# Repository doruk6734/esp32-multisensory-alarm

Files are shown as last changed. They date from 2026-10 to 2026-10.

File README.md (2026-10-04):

# ESP32 Multisensory Alarm

An ESP32-S3 based alarm system that combines **high-power light, airflow, and an optional active buzzer** to create a configurable wake-up sequence.

The system includes Blynk remote control, an I2C LCD, physical buttons, status LEDs, custom CAD, and an electrical schematic.

<p align="center">
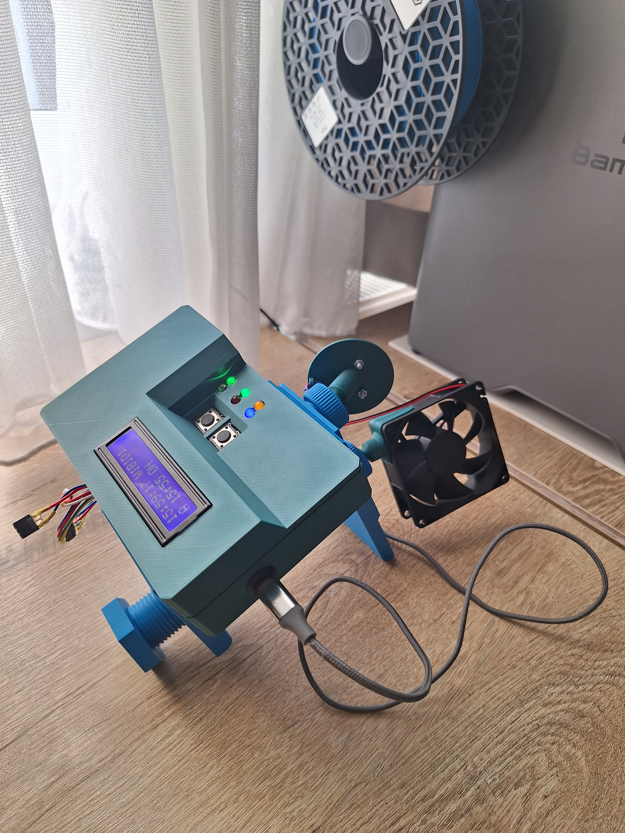
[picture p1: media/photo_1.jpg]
  
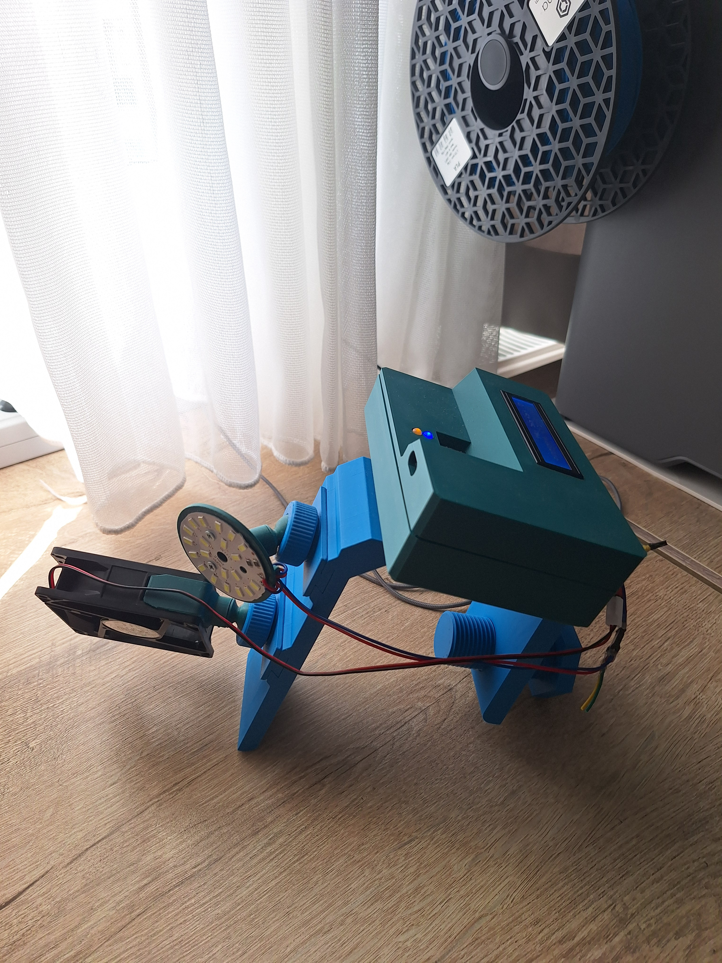
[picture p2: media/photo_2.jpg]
  
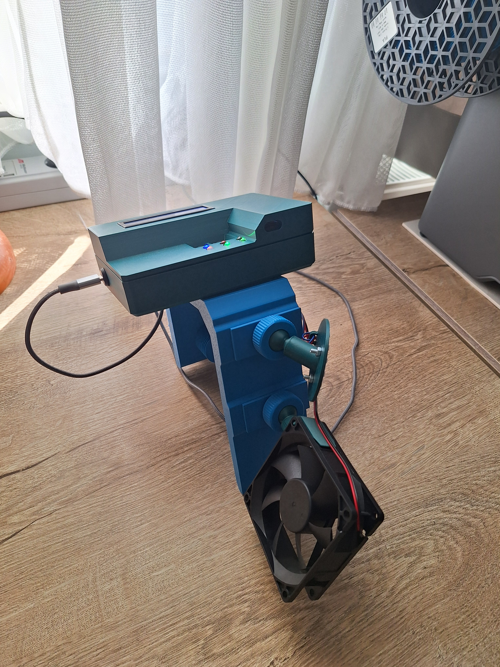
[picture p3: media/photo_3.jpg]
  
</p>

## Features

- ESP32-S3 controller
- 10 W LED with PWM brightness control
- Fan-based airflow
- Optional removable active buzzer
- Configurable alarm time, duration, repeats, and intensity
- Blynk remote control
- NTP time synchronization
- 16x2 I2C LCD
- Physical controls and status LEDs
- Custom 3D-printed enclosure
- Hardware test firmware
- CAD and schematic files included

## Demo

[Watch the demonstration](media/demonstration.mp4)

## Hardware

Main components:

- ESP32-S3
- 10 W LED
- MX1508 driver
- 12 V fan
- Optional active buzzer
- 16x2 I2C LCD
- Two pushbuttons
- Status LEDs
- MOSFETs

Electrical schematic:

[ESP32-S3 Alarm Schematic](hardware/esp32s3-alarm-schematic.pdf)

CAD files:

`hardware/cad-files/`

## Firmware

Main firmware:

`firmware/alarm.ino`

Hardware test:

`firmware/hardware-test.ino`

The firmware handles:

- alarm scheduling
- progressive light patterns
- fan ramping
- Blynk synchronization
- Wi-Fi reconnection
- LCD interface
- status LEDs
- physical buttons

## License

This is an open-source hardware and software project.

- **Firmware:** [MIT License](LICENSES/MIT.txt)
- **Hardware and CAD:** [CERN-OHL-P-2.0](LICENSES/CERN-OHL-P-2.0.txt)
- **Documentation and original media:** [CC BY 4.0](LICENSES/CC-BY-4.0.txt)

Contributions are welcome.

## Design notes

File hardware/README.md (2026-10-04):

# Hardware

The hardware designs in this directory, including the schematic and CAD
files, are licensed under the CERN Open Hardware Licence Version 2 -
Permissive.

SPDX-License-Identifier: CERN-OHL-P-2.0

See `../LICENSES/CERN-OHL-P-2.0.txt`.

## Contents

- Electrical schematic
- Complete alarm assembly
- Electronics enclosure
- Fan mounting components
- Light mounting components
- Mechanical connection components

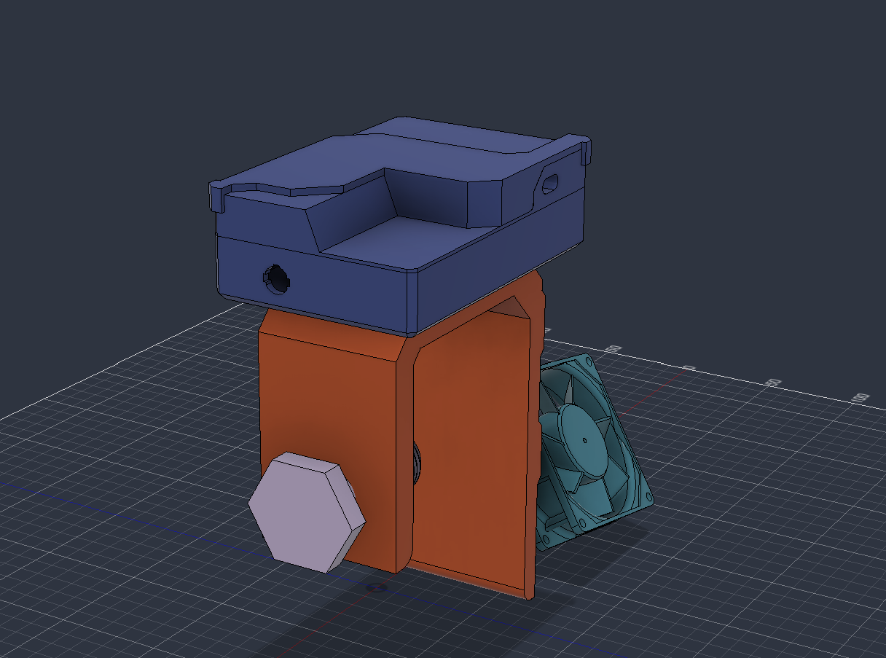
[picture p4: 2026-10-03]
hardware/alarm_image_3.png

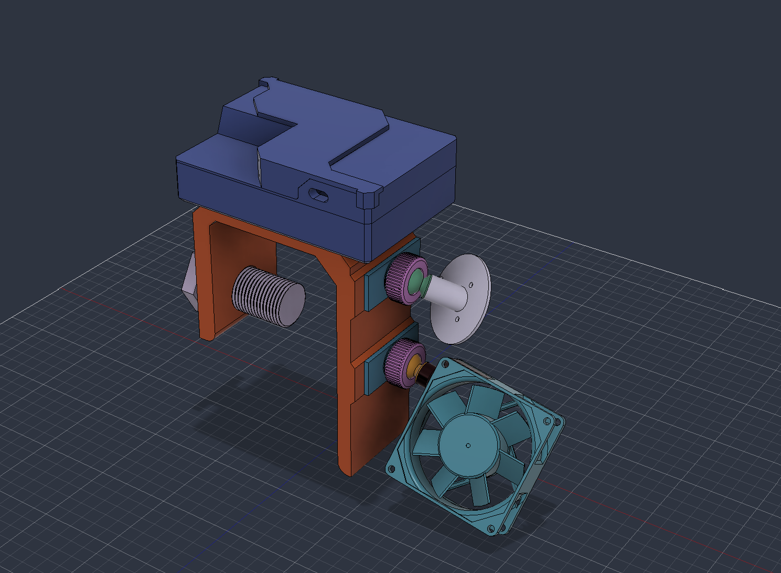
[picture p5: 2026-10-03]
hardware/alarm_image_2.png

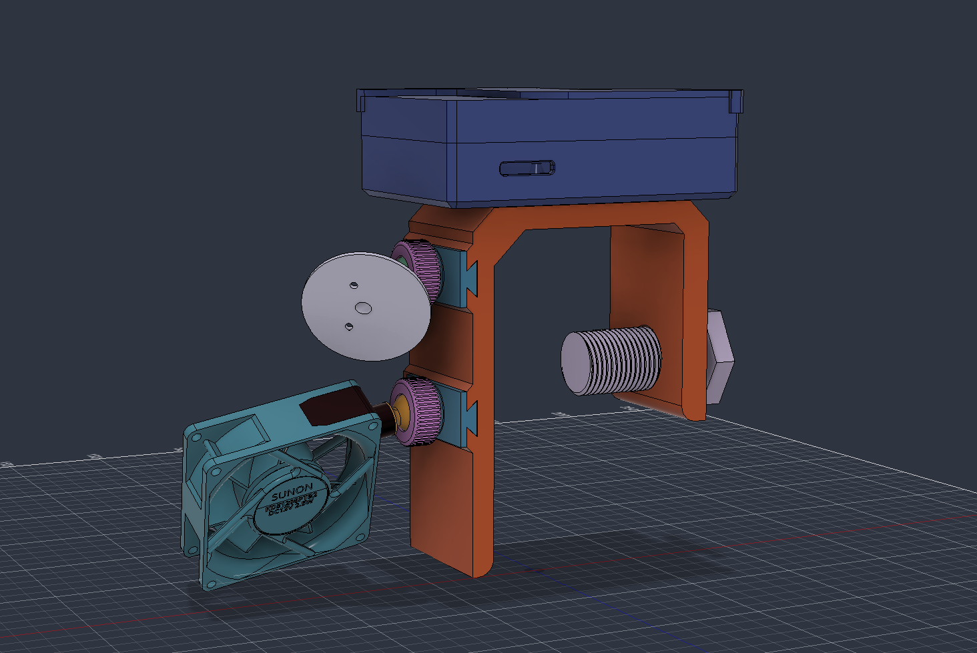
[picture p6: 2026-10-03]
hardware/alarm_image_1.png

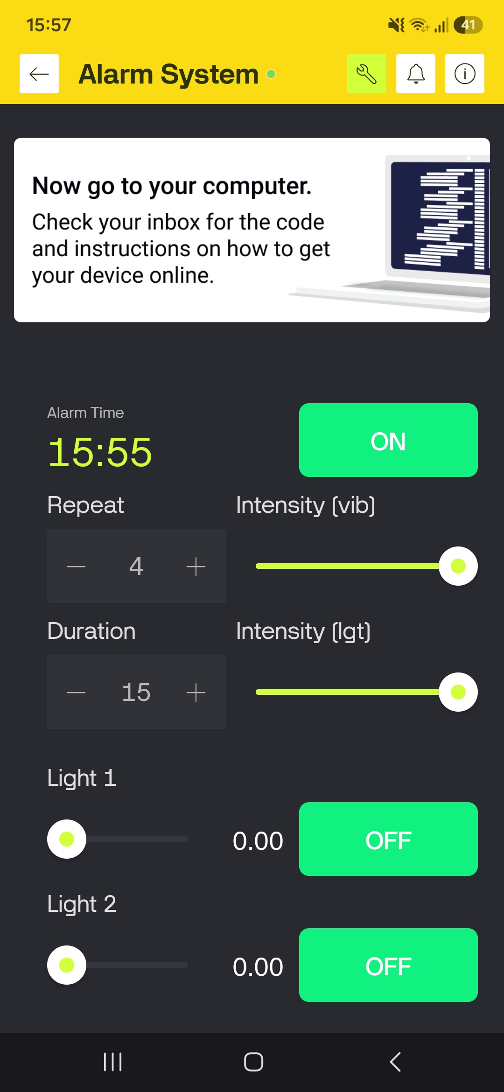
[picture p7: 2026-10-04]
media/Screenshot_Blynk IoT.jpg

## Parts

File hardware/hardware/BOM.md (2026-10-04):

# Bill of Materials

| Component | Quantity | Notes |
|---|---:|---|
| ESP32-S3 DevKit | 1 | Main controller |
| 10 W LED | 1 | Wake light |
| MX1508 | 1 | LED control |
| 12 V fan | 1 | Airflow |
| 16x2 I2C LCD | 1 | 0x27 |
| Active buzzer | 1 | Optional |
| Pushbutton | 2 | User controls |
| Status LEDs | 6 | System indicators |
| 10K Resistors | 8 | LED protection and MOSFET control |
| I2C Level Shifter | 1 | Powering the LCD with 3.3V outputs |
| Buck Converter | 1 | Regulating the power |
| Boost Converter | 1 | Powering the fan |
| 2N700 MOSFETs | 2 | Controling the buzzer and the fan |
| USB-C jack | 1 | Power input |
| Capacitors | - | Decoupling and signal regulation |

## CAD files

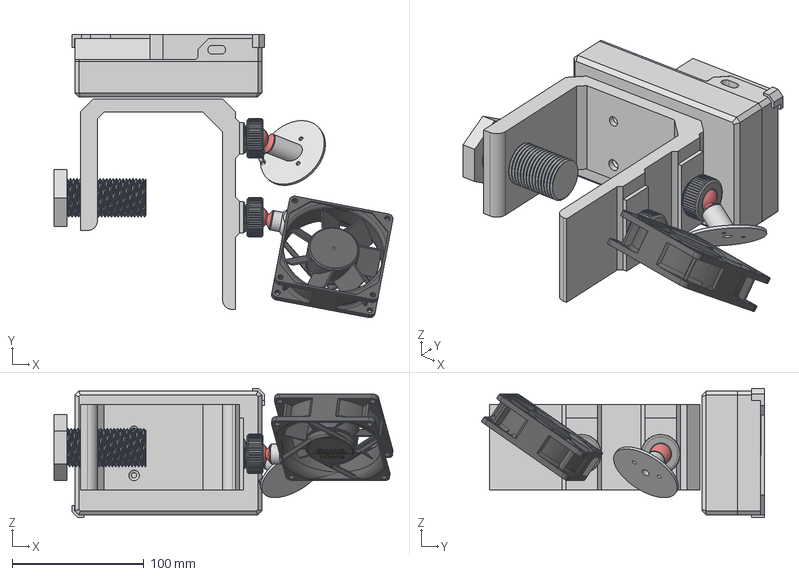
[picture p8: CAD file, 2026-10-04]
hardware/cad-files/alarm_assembly.step
257.5 x 215.2 x 98.0 mm
Screw x 2
Ball
Ball_1
80mm brushless fan (SUNON KDE1208PTB2)

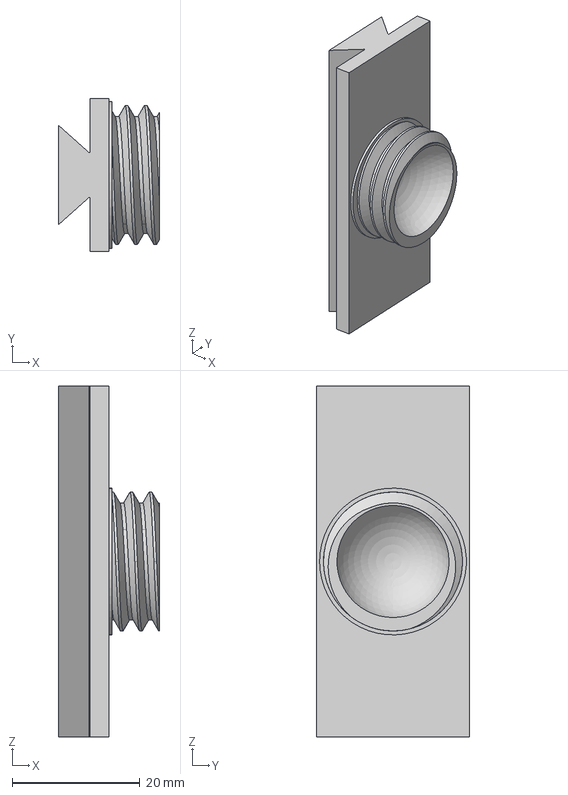
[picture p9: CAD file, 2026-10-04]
hardware/cad-files/base_connection.step
15.8 x 24.0 x 55.0 mm

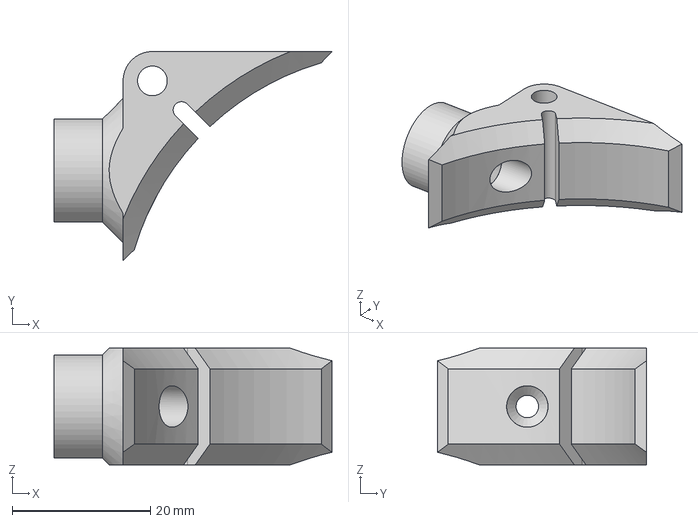
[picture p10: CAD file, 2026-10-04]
hardware/cad-files/fan_connection_1.step
40.2 x 30.2 x 16.9 mm

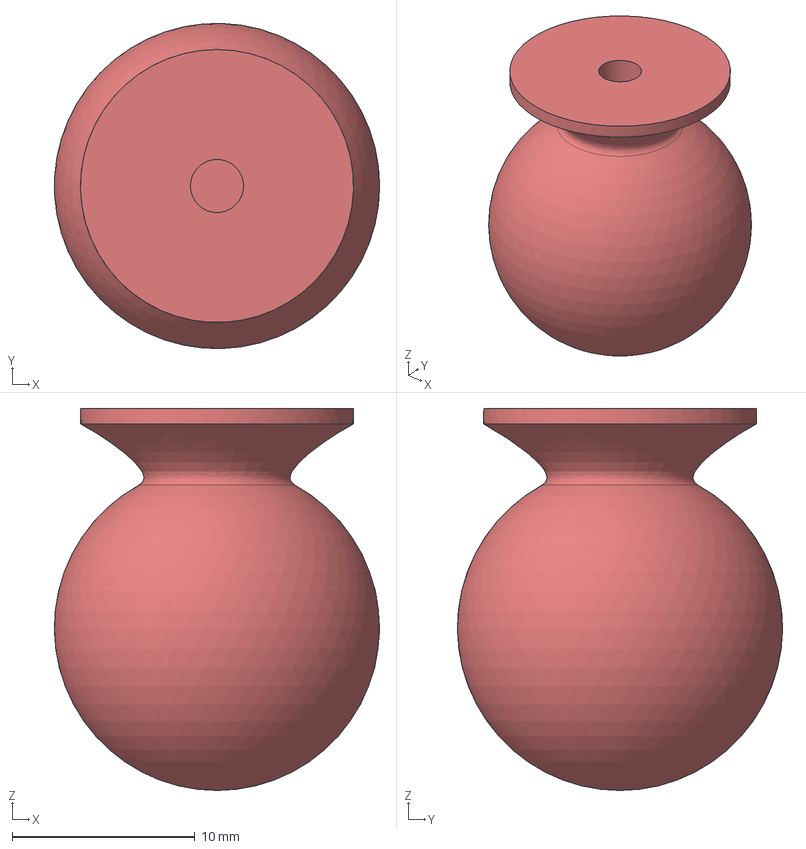
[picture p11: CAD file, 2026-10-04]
hardware/cad-files/fan_connection_2.step
17.8 x 17.8 x 20.9 mm

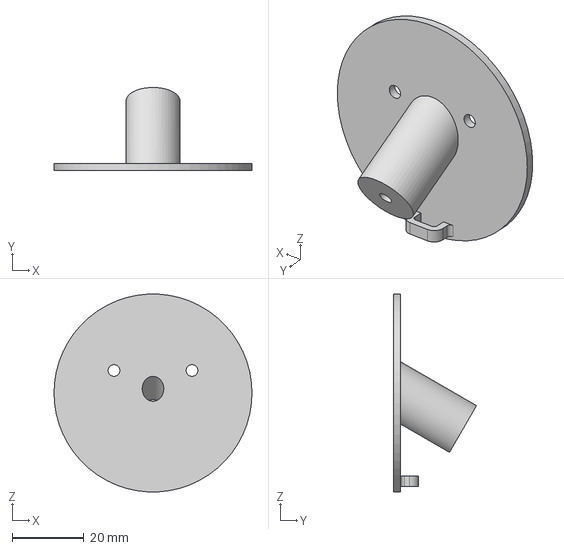
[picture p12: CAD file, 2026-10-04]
hardware/cad-files/light_holder.step
55.0 x 23.1 x 54.9 mm

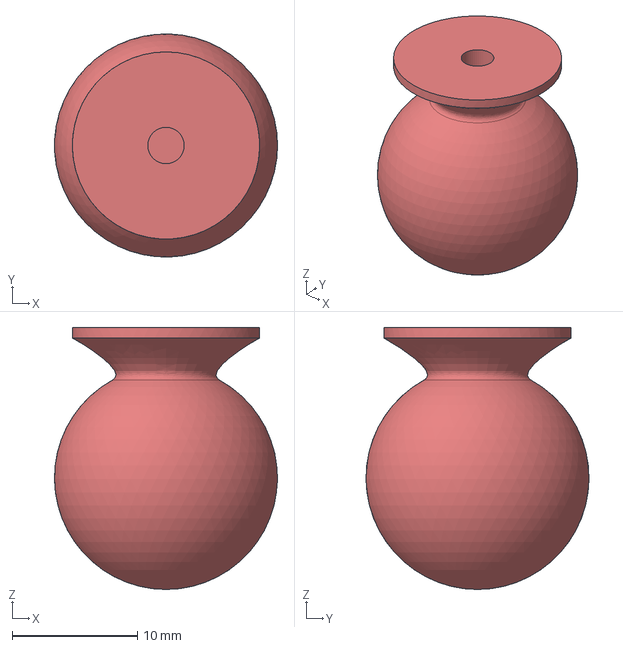
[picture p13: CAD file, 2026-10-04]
hardware/cad-files/light_connection.step
17.8 x 17.8 x 20.9 mm

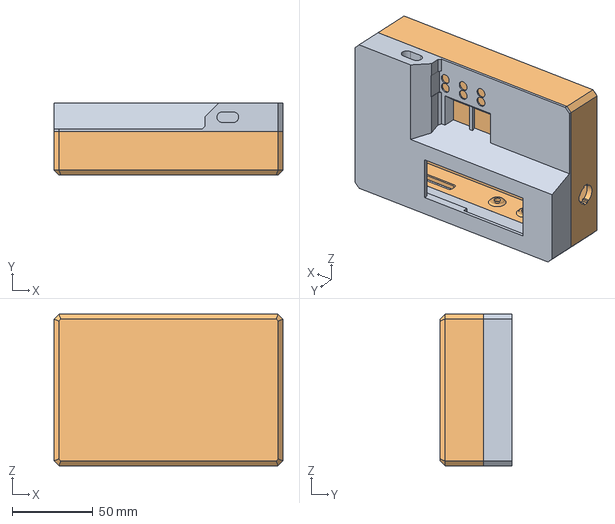
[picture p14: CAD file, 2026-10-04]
hardware/cad-files/electronics_case_1.step
142.0 x 44.5 x 94.0 mm

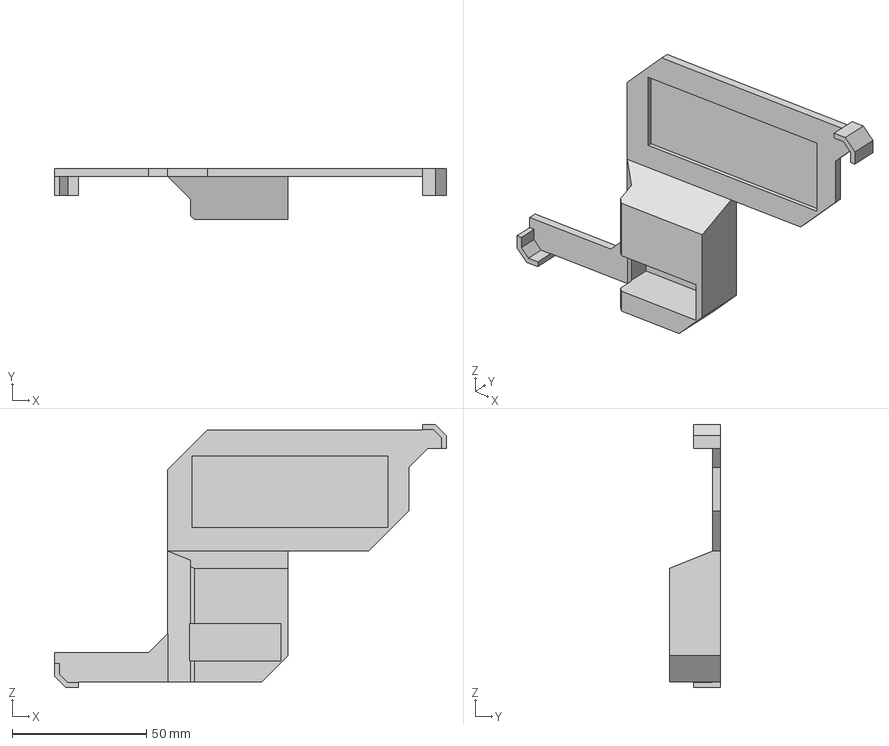
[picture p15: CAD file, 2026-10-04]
hardware/cad-files/electonics_case_cap.step
146.0 x 19.0 x 98.0 mm

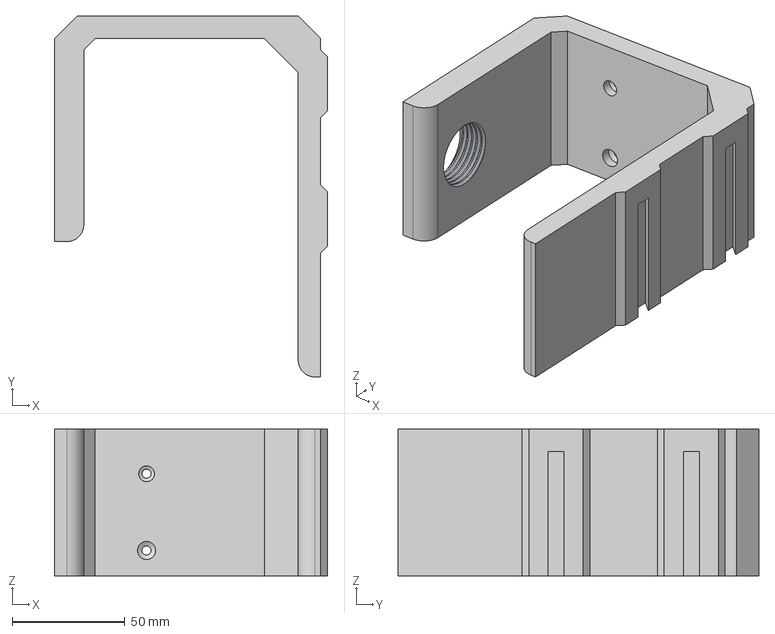
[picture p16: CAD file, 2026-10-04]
hardware/cad-files/base.step
121.0 x 160.0 x 65.0 mm

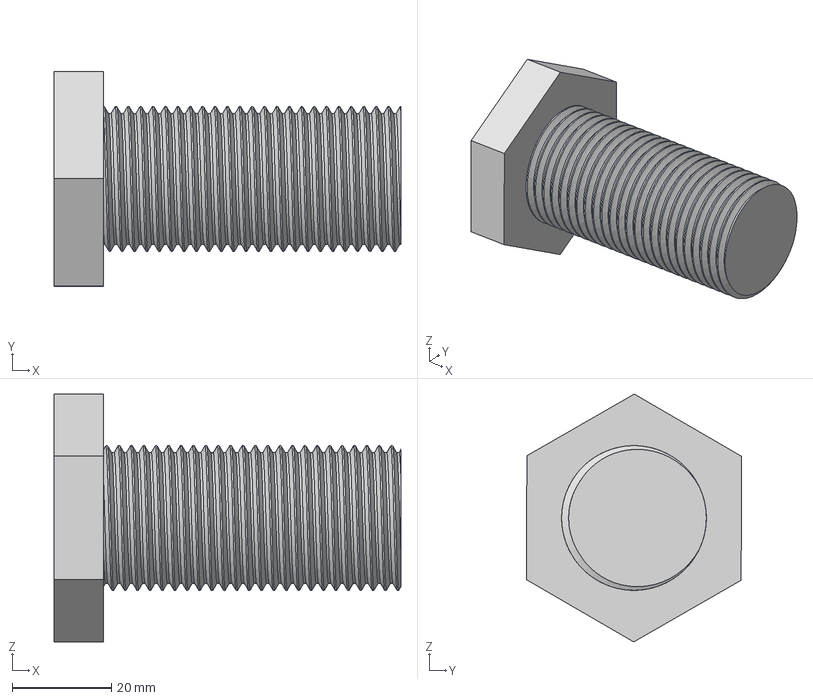
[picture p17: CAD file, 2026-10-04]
hardware/cad-files/screw.step
70.0 x 43.4 x 50.0 mm

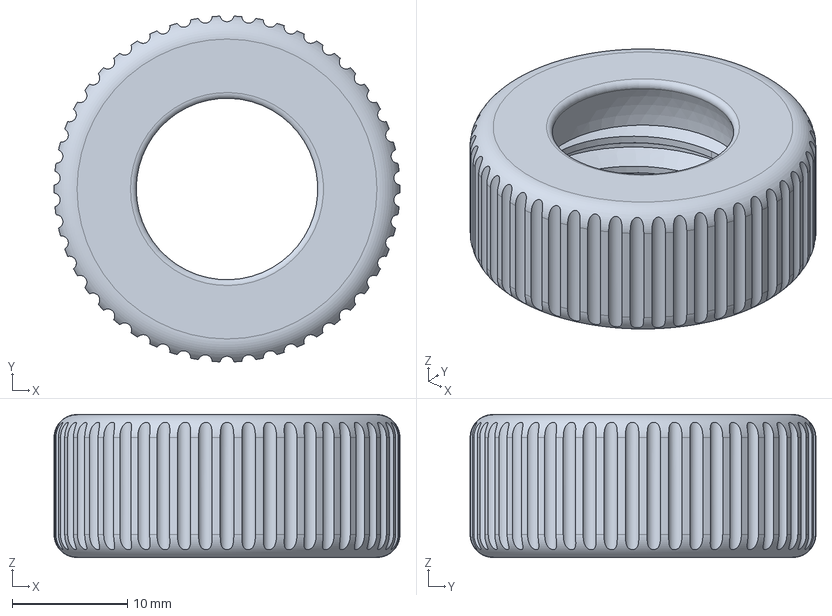
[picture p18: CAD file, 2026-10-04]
hardware/cad-files/ball_joint_screw.step
30.0 x 30.0 x 12.4 mm

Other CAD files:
hardware/cad-files/electronics_case_2.step

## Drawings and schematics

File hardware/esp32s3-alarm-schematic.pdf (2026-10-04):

# 01 - Power and loads

## POWER INPUT AND 5 V BUS

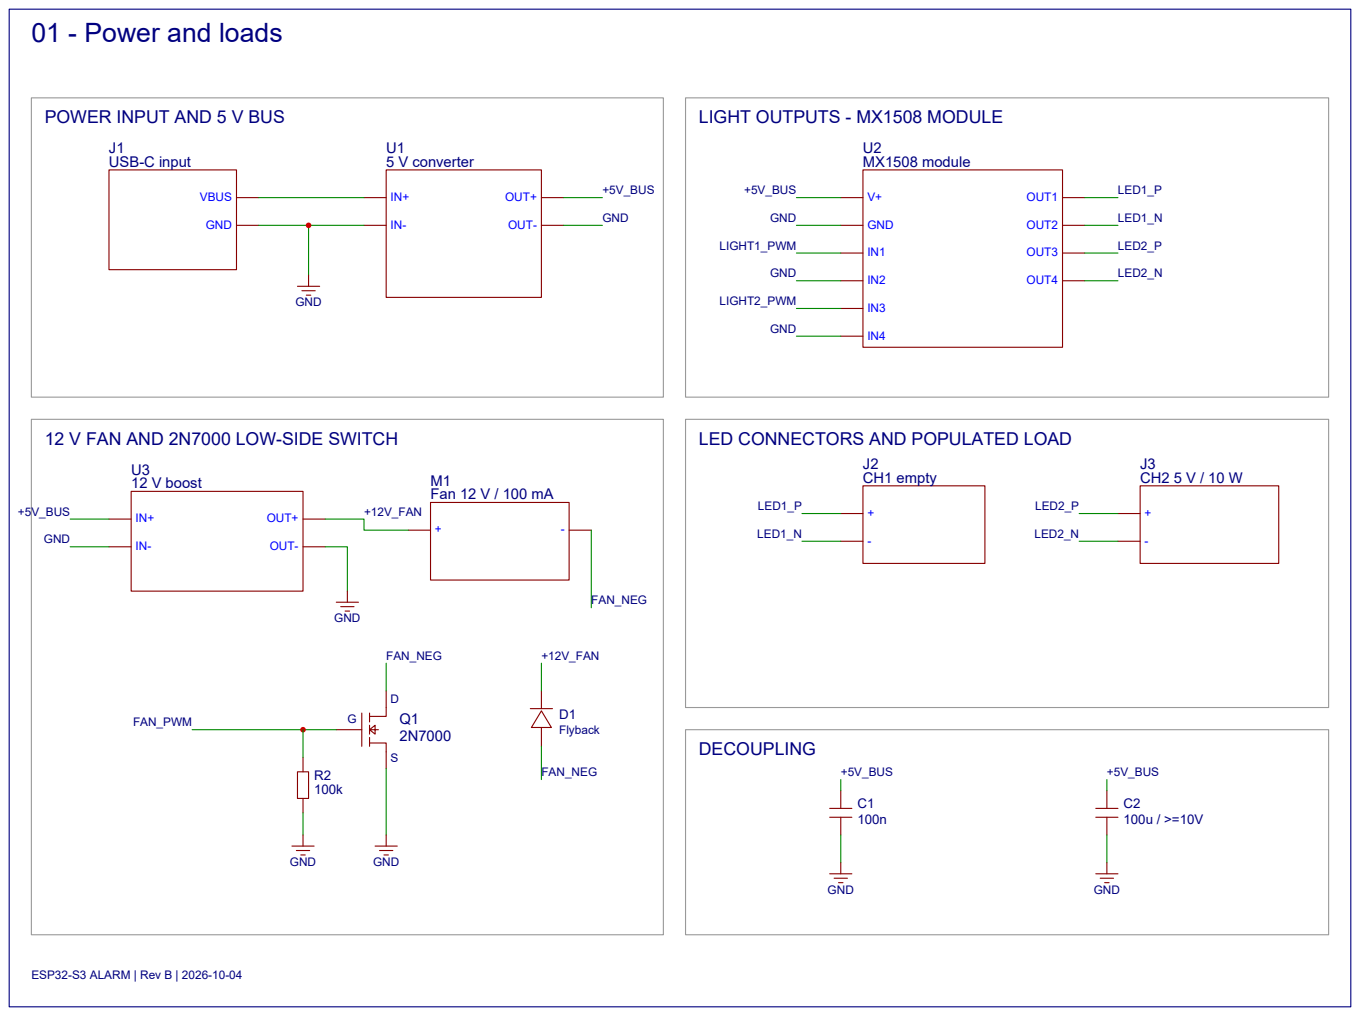
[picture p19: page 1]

12 V FAN AND 2N7000 LOW-SIDE SWITCH

LED CONNECTORS AND POPULATED LOAD

# 02 - Controller and user interface

## ESP32-S3 BOARD INTERFACE

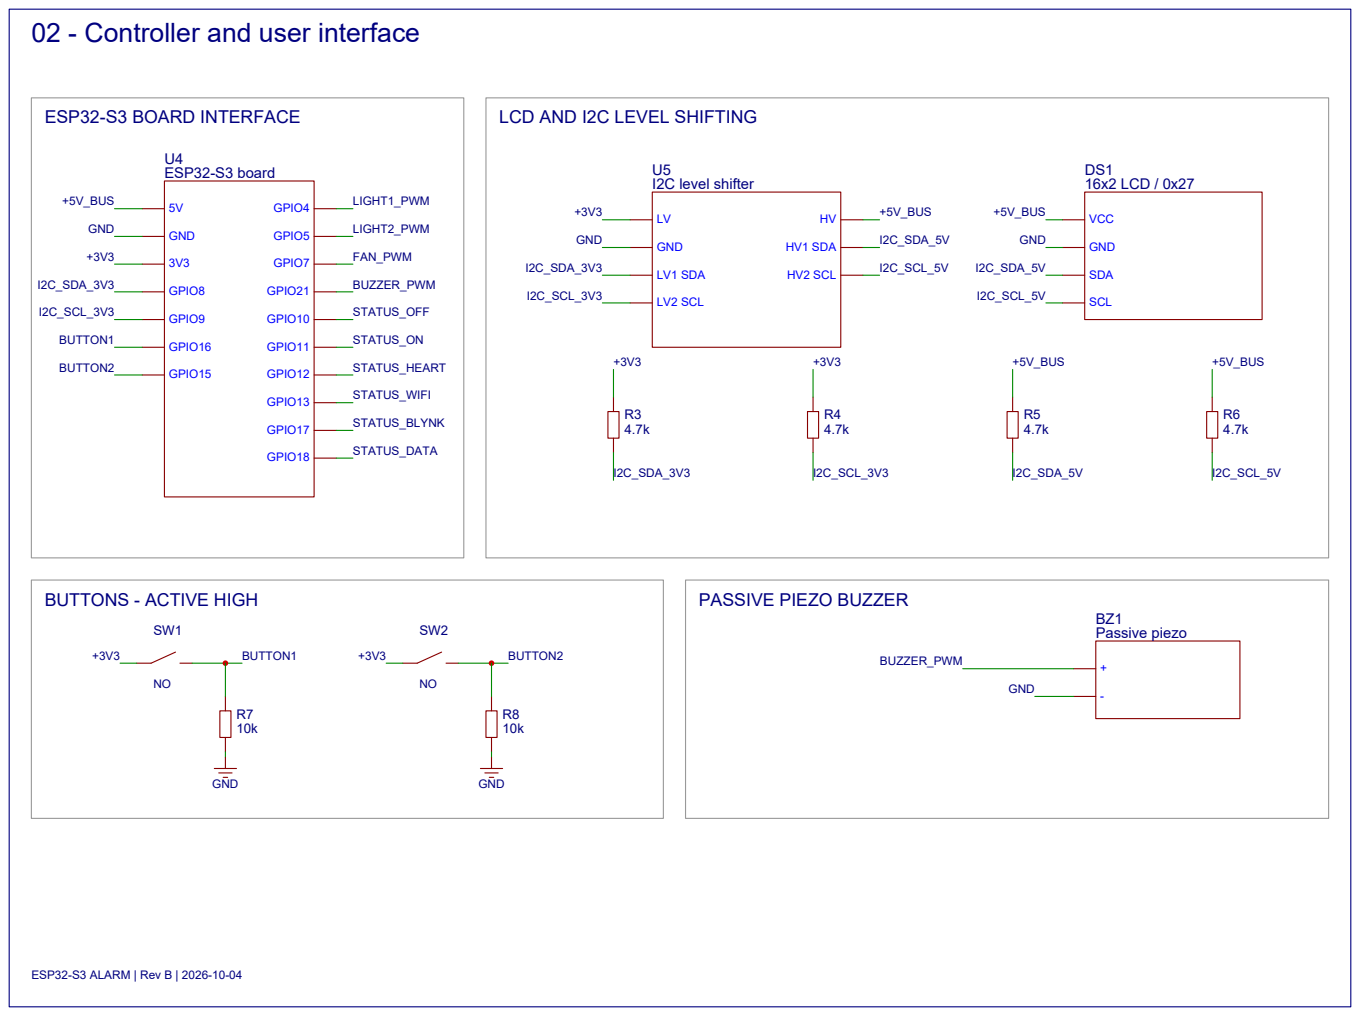
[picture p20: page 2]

LCD AND I2C LEVEL SHIFTING

# 03 - Status indicators

## ALARM OFF / GPIO10

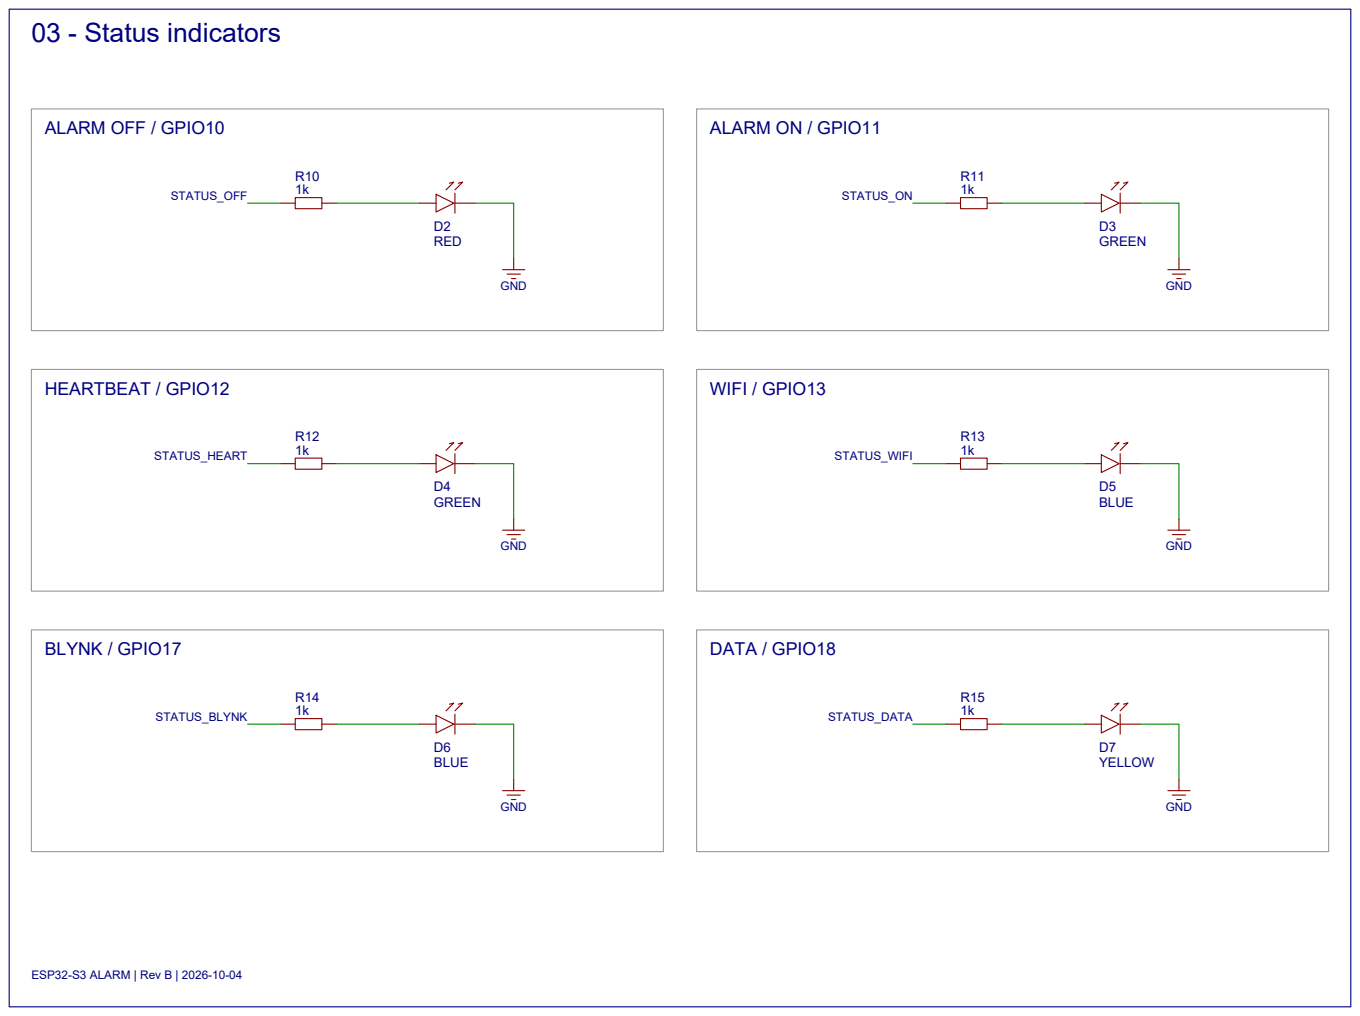
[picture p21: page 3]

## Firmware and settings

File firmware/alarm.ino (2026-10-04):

// SPDX-License-Identifier: MIT
// Copyright (c) 2026 Doruk Garip

#define BLYNK_TEMPLATE_ID "TMPL60t_yvDvl"
#define BLYNK_TEMPLATE_NAME "Quickstart Template"
#define BLYNK_AUTH_TOKEN "" // Enter your token

#define BLYNK_PRINT Serial 

#include <Wire.h>
#include <LiquidCrystal_I2C.h>
#include <WiFi.h>
#include <BlynkSimpleEsp32.h>
#include <time.h>
#include <math.h>

// ====================================================
// WIFI
// ====================================================

char ssid[] = ""; // Enter your WIFI name
char pass[] = ""; // Enter your WIFI password

bool wifiWasConnected = false;

unsigned long lastWiFiAttempt = 0;
unsigned long lastBlynkAttempt = 0;

const unsigned long WIFI_RETRY_INTERVAL = 10000;
const unsigned long BLYNK_RETRY_INTERVAL = 10000;

// ====================================================
// LCD
// ====================================================

#define SDA_PIN 8
#define SCL_PIN 9

LiquidCrystal_I2C lcd(0x27, 16, 2);

const unsigned long LCD_UPDATE_INTERVAL = 250;
const unsigned long LCD_FORCE_UPDATE_INTERVAL = 5000;
const unsigned long LCD_RECOVERY_INTERVAL = 60000;

unsigned long previousLCDUpdate = 0;
unsigned long previousLCDForceUpdate = 0;
unsigned long previousLCDRecovery = 0;

char lastLCDLine0[17] = "";
char lastLCDLine1[17] = "";

// ====================================================
// BUTTONS
// ====================================================

#define BUTTON_1_PIN 16
#define BUTTON_2_PIN 15

#define BUTTON_PRESSED_STATE HIGH

const unsigned long DEBOUNCE_TIME = 30;
const unsigned long RESET_HOLD_TIME = 2000;

struct Button {
  int pin;
  int stableState;
  int lastRawState;
  unsigned long lastRawChange;
  bool pressEvent;
};

Button button1;
Button button2;

bool bothButtonsHolding = false;
unsigned long bothButtonsStart = 0;

// ====================================================
// 10W LED / MX1508
// ====================================================

#define LIGHT_1_PIN 4
#define LIGHT_2_PIN 5

const int LIGHT_PWM_FREQUENCY = 1000;
const int LIGHT_PWM_RESOLUTION = 8;

// 178 / 255 = 69.8% maximum duty cycle
const uint32_t LIGHT_MAX_PWM = 160;

// ====================================================
// FAN
// ====================================================

#define FAN_PIN 7

const int FAN_PWM_FREQUENCY = 20000;
const int FAN_PWM_RESOLUTION = 8;

// ====================================================
// BUZZER
// ====================================================

#define BUZZER_PIN 21

#define PASSIVE_BUZZER 1

const int BUZZER_FREQUENCY = 2200;
const int BUZZER_PWM_RESOLUTION = 8;

// ====================================================
// STATUS LEDS
// ====================================================

/*
  GPIO10 RED
    ON = alarm disabled

  GPIO11 GREEN
    ON = alarm enabled

  GPIO12
    heartbeat pulse = firmware alive

  GPIO13
    solid = WiFi connected
    blink = WiFi disconnected

  GPIO17 BLUE
    solid = Blynk connected
    blink = WiFi OK, Blynk disconnected
    off = no WiFi

  GPIO18 YELLOW
    solid = all Blynk data received
    fast blink = retrieving data
    double blink = sync timed out
    off = Blynk disconnected
*/

#define RED_LED_PIN       10
#define GREEN_LED_PIN     11
#define HEARTBEAT_LED_PIN 12
#define WIFI_LED_PIN      13
#define BLYNK_LED_PIN     17
#define DATA_LED_PIN      18

const int statusPatternLEDs[] = {
  HEARTBEAT_LED_PIN,
  WIFI_LED_PIN,
  BLYNK_LED_PIN,
  DATA_LED_PIN
};

const int statusPatternLEDCount =
  sizeof(statusPatternLEDs) /
  sizeof(statusPatternLEDs[0]);

// ====================================================
// BLYNK VALUES
// ====================================================

// V0
int alarmActive = 0;

// V1
int light1Active = 0;

// V2
int light2Active = 0;

// V3
// Additional repeats.
// 0 = only first alarm
// 2 = first alarm + 2 repeats
int repeat = 0;

// V4
// Duration of EACH alarm burst in seconds
int duration = 30;

// V5
// Currently unused
double intensityVib = 0.0;

// V6
// Maximum alarm light intensity
double intensityLgt = 1.0;

// V7
double intensityLgt1 = 0.0;

// V8
double intensityLgt2 = 0.0;

// V9
// Seconds from midnight as String
String alarmTime = "";

// ====================================================
// BLYNK SYNC
// ====================================================

bool receivedPins[10] = {false};
bool allDataReceived = false;
bool syncTimedOut = false;

unsigned long blynkSyncStart = 0;
unsigned long previousBlynkResync = 0;

const unsigned long BLYNK_SYNC_TIMEOUT = 8000;
const unsigned long BLYNK_RESYNC_INTERVAL = 10000;

// ====================================================
// BLYNK DATA LED ANIMATION
// ====================================================

bool dataPatternActive = false;
unsigned long dataPatternStart = 0;

const unsigned long DATA_PATTERN_STEP = 90;
const int DATA_PATTERN_STEPS = 8;

// ====================================================
// CLOCK
// ====================================================

const long GMT_OFFSET = 3 * 3600;

bool ntpConfigured = false;

const int ALARM_TRIGGER_WINDOW = 60;

// ====================================================
// LCD PAGE
// ====================================================

bool showClockPage = true;
int currentPage = -1;

// ====================================================
// ALARM STATE
// ====================================================

bool alarmSequenceActive = false;
bool alarmBurstOn = false;

int currentAlarmBurst = 0;

unsigned long alarmPhaseStart = 0;

const unsigned long ALARM_REPEAT_GAP = 10000;

int lastAlarmDateKey = -1;

// ====================================================
// SMOOTH LIGHT BREATHING STATE
// ====================================================

double lightBreathPhase = 0.0;
unsigned long previousLightBreathUpdate = 0;

// ====================================================
// GENERAL HELPERS
// ====================================================

double clamp01(double value)
{
  if (value < 0.0) return 0.0;
  if (value > 1.0) return 1.0;

  return value;
}

uint32_t intensityToPWM(double intensity)
{
  intensity = clamp01(intensity);

  return (uint32_t)(
    LIGHT_MAX_PWM * intensity + 0.5
  );
}

// ====================================================
// LCD HELPERS
// ====================================================

void invalidateLCDCache()
{
  lastLCDLine0[0] = '\0';
  lastLCDLine1[0] = '\0';
}

void writeLCDLine(
  int row,
  const char *text,
  bool force = false
)
{
  char formatted[17];

  snprintf(
    formatted,
    sizeof(formatted),
    "%-16.16s",
    text
  );

  char *cache =
    row == 0
    ? lastLCDLine0
    : lastLCDLine1;

  if (
    force ||
    strcmp(formatted, cache) != 0
  )
  {
    lcd.setCursor(0, row);
    lcd.print(formatted);

    strcpy(cache, formatted);
  }
}

// ====================================================
// BLYNK STATE
// ====================================================

bool allBlynkDataReceived()
{
  for (int i = 0; i < 10; i++) {

    if (!receivedPins[i])
      return false;
  }

  return true;
}

bool alarmDataReady()
{
  return
    receivedPins[0] &&
    receivedPins[3] &&
    receivedPins[4] &&
    receivedPins[6] &&
    receivedPins[9];
}

void startDataPattern()
{
  dataPatternActive = true;
  dataPatternStart = millis();
}

// ====================================================
// BLYNK CALLBACK
// ====================================================

BLYNK_WRITE_DEFAULT()
{
  int pin = request.pin;

  if (pin < 0 || pin > 9)
    return;

  receivedPins[pin] = true;

  switch (pin) {

    case 0:
      alarmActive = param.asInt();

      Serial.printf(
        "V0 Alarm Active = %d\n",
        alarmActive
      );
      break;

    case 1:
      light1Active = param.asInt();

      Serial.printf(
        "V1 Light 1 Active = %d\n",
        light1Active
      );
      break;

    case 2:
      light2Active = param.asInt();

      Serial.printf(
        "V2 Light 2 Active = %d\n",
        light2Active
      );
      break;

    case 3:
      repeat = param.asInt();

      Serial.printf(
        "V3 Repeat = %d\n",
        repeat
      );
      break;

    case 4:
      duration = param.asInt();

      Serial.printf(
        "V4 Duration = %d sec\n",
        duration
      );
      break;

    case 5:
      intensityVib = param.asDouble();

      Serial.printf(
        "V5 Vib = %.2f\n",
        intensityVib
      );
      break;

    case 6:
      intensityLgt = param.asDouble();

      Serial.printf(
        "V6 Alarm Light = %.2f\n",
        intensityLgt
      );
      break;

    case 7:
      intensityLgt1 = param.asDouble();

      Serial.printf(
        "V7 Light1 Int = %.2f\n",
        intensityLgt1
      );
      break;

    case 8:
      intensityLgt2 = param.asDouble();

      Serial.printf(
        "V8 Light2 Int = %.2f\n",
        intensityLgt2
      );
      break;

    case 9:
      alarmTime = param.asStr();

      Serial.printf(
        "V9 Alarm Time = %s\n",
        alarmTime.c_str()
      );
      break;
  }

  bool previousAllData =
    allDataReceived;

  allDataReceived =
    allBlynkDataReceived();

  if (allDataReceived) {

    if (
      !previousAllData ||
      Blynk.connected()
    )
    {
      startDataPattern();
    }
  }
}

// ====================================================
// BLYNK CONNECTED
// ====================================================

BLYNK_CONNECTED()
{
  Serial.println();
  Serial.println("BLYNK CONNECTED");
  Serial.println("Retrieving V0-V9");

  for (int i = 0; i < 10; i++) {
    receivedPins[i] = false;
  }

  allDataReceived = false;
  syncTimedOut = false;

  dataPatternActive = false;

  blynkSyncStart = millis();
  previousBlynkResync = millis();

  Blynk.syncVirtual(
    V0,
    V1,
    V2,
    V3,
    V4,
    V5,
    V6,
    V7,
    V8,
    V9
  );
}

// ====================================================
// NTP
// ====================================================

void configureNTP()
{
  if (ntpConfigured)
    return;

  configTime(
    GMT_OFFSET,
    0,
    "pool.ntp.org",
    "time.google.com"
  );

  ntpConfigured = true;

  Serial.println(
    "NTP configured"
  );

  struct tm timeInfo;

  if (
    getLocalTime(
      &timeInfo,
      2000
    )
  )
  {
    Serial.printf(
      "Clock: %02d:%02d:%02d\n",
      timeInfo.tm_hour,
      timeInfo.tm_min,
      timeInfo.tm_sec
    );
  }

  else {

    Serial.println(
      "NTP not synchronized yet"
    );
  }
}

// ====================================================
// NETWORK MANAGEMENT
// ====================================================

void attemptBlynkConnection()
{
  if (
    WiFi.status() != WL_CONNECTED ||
    Blynk.connected()
  )
  {
    return;
  }

  Serial.println(
    "Trying Blynk..."
  );

  if (
    Blynk.connect(1000)
  )
  {
    Serial.println(
      "Blynk connected"
    );
  }

  else {

    Serial.println(
      "Blynk connection failed"
    );
  }
}

void maintainConnections(
  unsigned long now
)
{
  bool wifiConnected =
    WiFi.status() ==
    WL_CONNECTED;

  if (
    wifiConnected &&
    !wifiWasConnected
  )
  {
    Serial.println();
    Serial.println(
      "WiFi connected"
    );

    Serial.print(
      "IP: "
    );

    Serial.println(
      WiFi.localIP()
    );

    configureNTP();

    lastBlynkAttempt = 0;
  }

  if (
    !wifiConnected &&
    wifiWasConnected
  )
  {
    Serial.println(
      "WiFi disconnected"
    );
  }

  wifiWasConnected =
    wifiConnected;

  if (!wifiConnected) {

    if (
      now - lastWiFiAttempt >=
      WIFI_RETRY_INTERVAL
    )
    {
      lastWiFiAttempt = now;

      Serial.println(
        "Retrying WiFi..."
      );

      WiFi.disconnect();

      WiFi.begin(
        ssid,
        pass
      );
    }

    return;
  }

  if (Blynk.connected()) {

    Blynk.run();
  }

  else {

    if (
      !alarmSequenceActive &&
      now - lastBlynkAttempt >=
      BLYNK_RETRY_INTERVAL
    )
    {
      lastBlynkAttempt = now;

      attemptBlynkConnection();
    }
  }
}

// ====================================================
// BLYNK RESYNC
// ====================================================

void maintainBlynkSync(
  unsigned long now
)
{
  if (!Blynk.connected())
    return;

  if (allDataReceived)
    return;

  if (
    !syncTimedOut &&
    now - blynkSyncStart >=
    BLYNK_SYNC_TIMEOUT
  )
  {
    syncTimedOut = true;

    Serial.println(
      "Blynk data sync timed out"
    );
  }

  if (
    now - previousBlynkResync >=
    BLYNK_RESYNC_INTERVAL
  )
  {
    previousBlynkResync = now;

    Serial.println(
      "Retrying Blynk data sync"
    );

    Blynk.syncVirtual(
      V0,
      V1,
      V2,
      V3,
      V4,
      V5,
      V6,
      V7,
      V8,
      V9
    );
  }
}

// ====================================================
// ALARM TIME
// ====================================================

bool getAlarmSeconds(
  int &secondsOut
)
{
  if (alarmTime.length() == 0)
    return false;

  for (
    unsigned int i = 0;
    i < alarmTime.length();
    i++
  )
  {
    if (
      alarmTime[i] < '0' ||
      alarmTime[i] > '9'
    )
    {
      return false;
    }
  }

  long value =
    alarmTime.toInt();

  if (
    value < 0 ||
    value >= 86400
  )
  {
    return false;
  }

  secondsOut =
    (int)value;

  return true;
}

void secondsToClock(
  int seconds,
  char *buffer,
  size_t bufferSize
)
{
  if (
    seconds < 0 ||
    seconds >= 86400
  )
  {
    snprintf(
      buffer,
      bufferSize,
      "--:--"
    );

    return;
  }

  int hour =
    seconds / 3600;

  int minute =
    (seconds % 3600)
    / 60;

  snprintf(
    buffer,
    bufferSize,
    "%02d:%02d",
    hour,
    minute
  );
}

// ====================================================
// BUTTONS
// ====================================================

void initializeButton(
  Button &button,
  int pin
)
{
  pinMode(
    pin,
    INPUT
  );

  int initial =
    digitalRead(pin);

  button.pin =
    pin;

  button.stableState =
    initial;

  button.lastRawState =
    initial;

  button.lastRawChange =
    millis();

  button.pressEvent =
    false;
}

void updateButton(
  Button &button,
  unsigned long now
)
{
  button.pressEvent = false;

  int raw =
    digitalRead(
      button.pin
    );

  if (
    raw !=
    button.lastRawState
  )
  {
    button.lastRawState =
      raw;

    button.lastRawChange =
      now;
  }

  if (
    now - button.lastRawChange >=
    DEBOUNCE_TIME
  )
  {
    if (
      raw !=
      button.stableState
    )
    {
      button.stableState =
        raw;

      if (
        button.stableState ==
        BUTTON_PRESSED_STATE
      )
      {
        button.pressEvent =
          true;
      }
    }
  }
}

bool buttonIsPressed(
  const Button &button
)
{
  return
    button.stableState ==
    BUTTON_PRESSED_STATE;
}

// ====================================================
// BUZZER
// ====================================================

void setBuzzerVolume(
  double volume
)
{
  volume =
    clamp01(volume);

#if PASSIVE_BUZZER

  uint32_t pwm =
    (uint32_t)(
      128.0 * volume
    );

  ledcWrite(
    BUZZER_PIN,
    pwm
  );

#else

  digitalWrite(
    BUZZER_PIN,
    volume > 0.05
      ? HIGH
      : LOW
  );

#endif
}

void silenceBuzzer()
{
  setBuzzerVolume(
    0.0
  );
}

// ====================================================
// ALARM PARAMETERS
// ====================================================

int getTotalAlarmBursts()
{
  return max(
    1,
    repeat + 1
  );
}

unsigned long getAlarmBurstDuration()
{
  return
    (unsigned long)
    max(1, duration)
    * 1000UL;
}

// ====================================================
// START / STOP ALARM
// ====================================================

void startAlarmSequence(
  unsigned long now,
  int dateKey
)
{
  alarmSequenceActive = true;
  alarmBurstOn = true;

  currentAlarmBurst = 0;

  alarmPhaseStart = now;

  lastAlarmDateKey =
    dateKey;

  lightBreathPhase = 0.0;
  previousLightBreathUpdate = now;

  Serial.println();
  Serial.println(
    "===================="
  );

  Serial.println(
    "ALARM STARTED"
  );

  Serial.printf(
    "Duration = %d sec\n",
    duration
  );

  Serial.printf(
    "Repeat = %d\n",
    repeat
  );

  Serial.printf(
    "Total bursts = %d\n",
    getTotalAlarmBursts()
  );

  Serial.println(
    "===================="
  );
}

void stopAlarmSequence(
  const char *reason
)
{
  if (!alarmSequenceActive)
    return;

  alarmSequenceActive = false;
  alarmBurstOn = false;

  ledcWrite(
    LIGHT_1_PIN,
    0
  );

  ledcWrite(
    LIGHT_2_PIN,
    0
  );

  ledcWrite(
    FAN_PIN,
    0
  );

  silenceBuzzer();

  lightBreathPhase = 0.0;

  Serial.print(
    "Alarm stopped: "
  );

  Serial.println(
    reason
  );
}

// ====================================================
// ALARM TRIGGER
// ====================================================

void checkAlarmTrigger(
  unsigned long now
)
{
  static unsigned long previousCheck = 0;

  if (
    now - previousCheck <
    250
  )
  {
    return;
  }

  previousCheck = now;

  if (!alarmActive)
    return;

  if (!alarmDataReady())
    return;

  if (alarmSequenceActive)
    return;

  int targetSeconds;

  if (
    !getAlarmSeconds(
      targetSeconds
    )
  )
  {
    return;
  }

  struct tm timeInfo;

  if (
    !getLocalTime(
      &timeInfo,
      10
    )
  )
  {
    return;
  }

  int secondsFromMidnight =
    timeInfo.tm_hour * 3600 +
    timeInfo.tm_min * 60 +
    timeInfo.tm_sec;

  int dateKey =
    (timeInfo.tm_year + 1900)
    * 1000 +
    timeInfo.tm_yday;

  if (
    dateKey ==
    lastAlarmDateKey
  )
  {
    return;
  }

  if (
    secondsFromMidnight >=
      targetSeconds &&

    secondsFromMidnight <
      targetSeconds +
      ALARM_TRIGGER_WINDOW
  )
  {
    startAlarmSequence(
      now,
      dateKey
    );
  }
}

// ====================================================
// ALARM SEQUENCE
// ====================================================

void updateAlarmSequence(
  unsigned long now
)
{
  if (!alarmSequenceActive)
    return;

  if (!alarmActive) {

    stopAlarmSequence(
      "disabled from Blynk"
    );

    return;
  }

  unsigned long burstDuration =
    getAlarmBurstDuration();

  int totalBursts =
    getTotalAlarmBursts();

  // ==================================================
  // ACTIVE BURST
  // ==================================================

  if (alarmBurstOn) {

    if (
      now - alarmPhaseStart >=
      burstDuration
    )
    {
      if (
        currentAlarmBurst + 1 >=
        totalBursts
      )
      {
        stopAlarmSequence(
          "completed"
        );
      }

      else {

        alarmBurstOn =
          false;

        alarmPhaseStart =
          now;

        ledcWrite(
          LIGHT_1_PIN,
          0
        );

        ledcWrite(
          LIGHT_2_PIN,
          0
        );

        ledcWrite(
          FAN_PIN,
          0
        );

        silenceBuzzer();
      }
    }
  }

  // ==================================================
  // GAP BETWEEN REPEATS
  // ==================================================

  else {

    if (
      now - alarmPhaseStart >=
      ALARM_REPEAT_GAP
    )
    {
      currentAlarmBurst++;

      alarmBurstOn =
        true;

      alarmPhaseStart =
        now;

      lightBreathPhase =
        0.0;

      previousLightBreathUpdate =
        now;
    }
  }
}

// ====================================================
// ALARM SEVERITY
// ====================================================

double getAlarmSeverity(
  unsigned long now
)
{
  if (
    !alarmSequenceActive ||
    !alarmBurstOn
  )
  {
    return 0.0;
  }

  unsigned long durationMs =
    getAlarmBurstDuration();

  double progress =
    (double)(
      now - alarmPhaseStart
    )
    /
    (double)durationMs;

  progress =
    clamp01(progress);

  double repeatBoost =
    currentAlarmBurst *
    0.15;

  return clamp01(
    progress * 0.85 +
    repeatBoost
  );
}

// ====================================================
// LIGHT BREATH PERIOD
//
// 0%   -> 4.0 sec
// 40%  -> 1.0 sec
// 100% -> 0.7 sec
// ====================================================

double getLightBreathPeriod(
  double progress
)
{
  progress =
    clamp01(progress);

  if (progress <= 0.40) {

    double section =
      progress /
      0.40;

    return
      4.0 + (1.0 - 4.0) * section;
  }

  double section =
    (
      progress -
      0.40
    )
    /
    0.60;

  return
    1.0 +
    (
      0.7 -
      1.0
    )
    *
    section;
}

// ====================================================
// SMOOTH 10W LED BREATHING
// ====================================================
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
void loop()
{
  unsigned long now =
    millis();

  maintainConnections(
    now
  );

  maintainBlynkSync(
    now
  );

  processButtons(
    now
  );

  checkAlarmTrigger(
    now
  );

  updateAlarmSequence(
    now
  );

  updateOutputs(
    now
  );

  updateBoardLEDs(
    now
  );

  updateLCD(
    now
  );

  maintainLCD(
    now
  );
}

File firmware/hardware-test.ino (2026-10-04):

// SPDX-License-Identifier: MIT
// Copyright (c) 2026 Doruk Garip

#include <Wire.h>
#include <LiquidCrystal_I2C.h>

// =========================
// I2C LCD
// =========================
#define SDA_PIN 8
#define SCL_PIN 9

LiquidCrystal_I2C lcd(0x27, 16, 2);

// =========================
// DIGITAL OUTPUT TEST PINS
// =========================
const int outputPins[] = {
  12,
  13,
  17,
  18,
  10,
  11
};

const int outputCount =
  sizeof(outputPins) / sizeof(outputPins[0]);

// =========================
// INPUT PINS
// =========================
#define INPUT_1 16
#define INPUT_2 15

// =========================
// FAN MOSFET
// =========================
#define FAN_PIN 7

// =========================
// 3W LED DRIVER INPUTS
// =========================
#define LED_1_PIN 4
#define LED_2_PIN 5

// =========================
// BUZZER
// =========================
#define BUZZER_PIN 21

// This code assumes an ACTIVE buzzer.
// HIGH = buzzer sounds
// LOW  = buzzer silent

// =========================
// PWM
// =========================
const int PWM_FREQUENCY = 1000;
const int PWM_RESOLUTION = 8;  // 0-255

// =========================
// TIMING
// =========================

// Output test
unsigned long previousOutputTime = 0;
const unsigned long OUTPUT_INTERVAL = 2000;
int currentOutput = 0;

// Fan test
unsigned long previousFanTime = 0;
const unsigned long FAN_INTERVAL = 1000;
bool fanState = false;

// PWM fade
unsigned long previousPWMTime = 0;
const unsigned long PWM_INTERVAL = 10;

int pwmValue = 0;
int pwmDirection = 1;

// Serial
unsigned long previousSerialTime = 0;
const unsigned long SERIAL_INTERVAL = 200;

// LCD
unsigned long previousLCDTime = 0;
const unsigned long LCD_INTERVAL = 200;


// ====================================================
// SETUP
// ====================================================

void setup() {

  Serial.begin(115200);

  // ==================================================
  // LCD
  // ==================================================

  Wire.begin(SDA_PIN, SCL_PIN);

  // Slower I2C is more tolerant of noise
  Wire.setClock(100000);

  lcd.init();
  lcd.backlight();

  lcd.setCursor(0, 0);
  lcd.print("ESP32 TEST");

  lcd.setCursor(0, 1);
  lcd.print("Starting...");


  // ==================================================
  // DIGITAL OUTPUTS
  // ==================================================

  for (int i = 0; i < outputCount; i++) {

    pinMode(
      outputPins[i],
      OUTPUT
    );

    digitalWrite(
      outputPins[i],
      LOW
    );
  }

  // Start with first output ON
  digitalWrite(
    outputPins[0],
    HIGH
  );


  // ==================================================
  // INPUTS
  // ==================================================
  //
  // Assumes buttons connect GPIO -> 3.3V when pressed.
  //
  // Therefore:
  //
  // released = LOW
  // pressed  = HIGH
  //
  // Internal pulldown prevents floating inputs.
  // ==================================================

  pinMode(
    INPUT_1,
    INPUT_PULLDOWN
  );

  pinMode(
    INPUT_2,
    INPUT_PULLDOWN
  );


  // ==================================================
  // FAN
  // ==================================================

  pinMode(
    FAN_PIN,
    OUTPUT
  );

  digitalWrite(
    FAN_PIN,
    LOW
  );


  // ==================================================
  // BUZZER
  // ==================================================

  pinMode(
    BUZZER_PIN,
    OUTPUT
  );

  digitalWrite(
    BUZZER_PIN,
    LOW
  );


  // ==================================================
  // 3W LED PWM
  // ESP32 Arduino Core 3.x
  // ==================================================

  ledcAttach(
    LED_1_PIN,
    PWM_FREQUENCY,
    PWM_RESOLUTION
  );

  ledcAttach(
    LED_2_PIN,
    PWM_FREQUENCY,
    PWM_RESOLUTION
  );

  ledcWrite(
    LED_1_PIN,
    0
  );

  ledcWrite(
    LED_2_PIN,
    0
  );


  delay(1000);

  lcd.clear();


  Serial.println();
  Serial.println("=========================");
  Serial.println("ESP32 hardware test start");
  Serial.println("=========================");
}


// ====================================================
// LOOP
// ====================================================

void loop() {

  unsigned long now =
    millis();


  // ==================================================
  // READ BUTTONS
  // ==================================================

  int input1State =
    digitalRead(INPUT_1);

  int input2State =
    digitalRead(INPUT_2);


  // ==================================================
  // BUZZER
  //
  // ON only while BOTH buttons are pressed
  // ==================================================

  bool buzzerState =
    input1State == HIGH &&
    input2State == HIGH;


  digitalWrite(
    BUZZER_PIN,
    buzzerState
      ? HIGH
      : LOW
  );


  // ==================================================
  // CYCLE DIGITAL OUTPUTS
  // ==================================================

  if (
    now - previousOutputTime >=
    OUTPUT_INTERVAL
  )
  {
    previousOutputTime =
      now;


    // Current output OFF
    digitalWrite(
      outputPins[currentOutput],
      LOW
    );


    // Next output
    currentOutput++;


    if (
      currentOutput >=
      outputCount
    )
    {
      currentOutput = 0;
    }


    // Next output ON
    digitalWrite(
      outputPins[currentOutput],
      HIGH
    );


    Serial.print(
      "Active output changed to GPIO "
    );

    Serial.println(
      outputPins[currentOutput]
    );
  }


  // ==================================================
  // FAN TEST
  //
  // Toggles ON/OFF every second
  // ==================================================

  if (
    now - previousFanTime >=
    FAN_INTERVAL
  )
  {
    previousFanTime =
      now;


    fanState =
      !fanState;


    digitalWrite(
      FAN_PIN,
      fanState
        ? HIGH
        : LOW
    );


    Serial.print(
      "Fan: "
    );

    Serial.println(
      fanState
        ? "ON"
        : "OFF"
    );
  }


  // ==================================================
  // 3W LED PWM FADE
  //
  // 0 -> 255 -> 0 continuously
  // ==================================================

  if (
    now - previousPWMTime >=
    PWM_INTERVAL
  )
  {
    previousPWMTime =
      now;


    pwmValue +=
      pwmDirection;


    if (pwmValue >= 255) {

      pwmValue = 255;
      pwmDirection = -1;
    }


    if (pwmValue <= 0) {

      pwmValue = 0;
      pwmDirection = 1;
    }


    ledcWrite(
      LED_1_PIN,
      pwmValue
    );


    ledcWrite(
      LED_2_PIN,
      pwmValue
    );
  }


  // ==================================================
  // SERIAL MONITOR
  // ==================================================

  if (
    now - previousSerialTime >=
    SERIAL_INTERVAL
  )
  {
    previousSerialTime =
      now;


    Serial.print(
      "OUT GPIO "
    );

    Serial.print(
      outputPins[currentOutput]
    );


    Serial.print(
      " | IN16="
    );
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

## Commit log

2026-10-03 Add README for ESP32 Multisensory Alarm project
2026-10-04 Add hardware test code for ESP32 with peripherals
    This file contains the hardware test code for an ESP32, including setup for I2C LCD, digital outputs, inputs, fan control, buzzer, and PWM for LED drivers.
    [hardware-test.ino]
2026-10-04 Enhance README with features and hardware details
    Expanded the README to include detailed features, hardware components, and firmware information for the ESP32-S3 multisensory alarm system.
2026-10-04 Add Bill of Materials for hardware components
